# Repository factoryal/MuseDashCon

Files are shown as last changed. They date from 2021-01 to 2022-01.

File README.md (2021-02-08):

# MuseDashCon
MuseDashCon은 게임 MuseDash를 플레이하기 위한 커스텀 컨트롤러입니다.  
ArcadeBoard Type A 기반으로 만들었습니다.

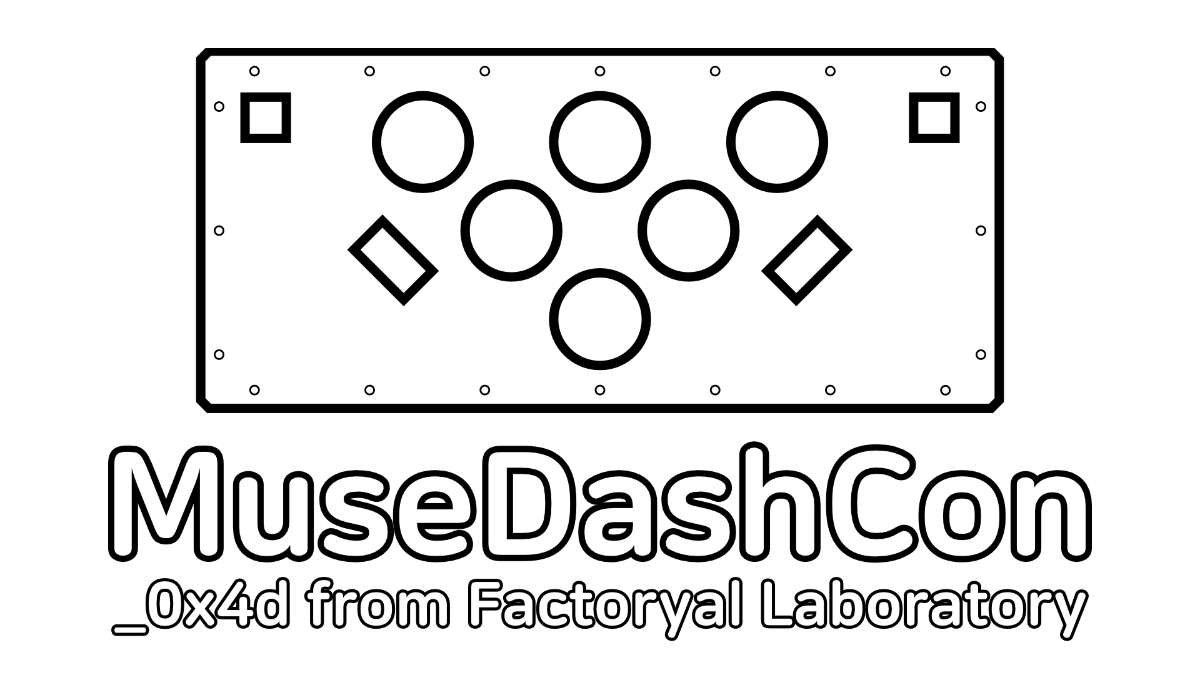
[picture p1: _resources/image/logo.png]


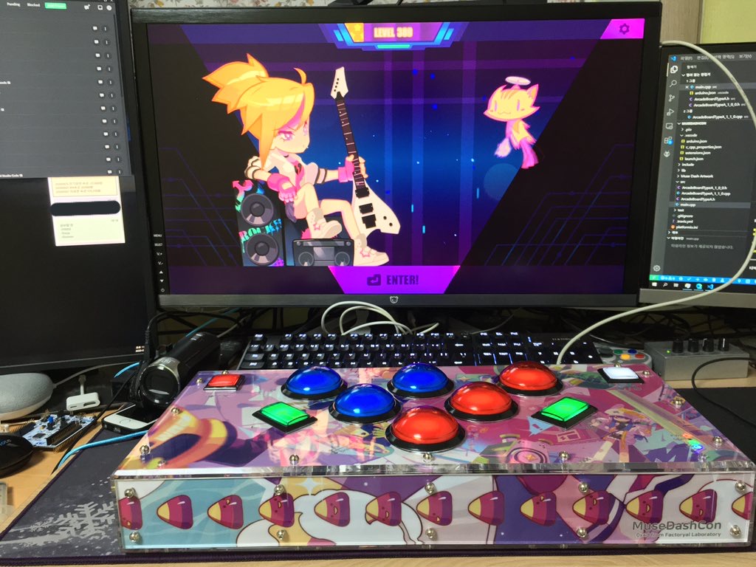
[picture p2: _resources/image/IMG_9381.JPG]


## Video
https://www.youtube.com/watch?v=jQfnqSeiyE0

[Muse Dash] Gaming Everything - Hard 8 w/ MuseDashCon (https://www.youtube.com/watch?v=-giunZwyiVg)

## Specs
Main Board: Arcade Board Type A v1.1.0 (Arduino Leonardo based)  
Button: IST 403, IST 405, IST 406 (GSM-V0303A06 Microswitch) (https://www.istmall.co.kr/goods/goods_list.php?cateCd=014008)  
Polling Rate: 1000Hz  
Interface: USB Type B  
Dimension: 460mm x 212mm x 74mm  

# Repository Includes...
**MuseDashCon** 리포지토리는 다음과 같은 자료가 저장되어 있습니다.

## Arduino 소스코드 (ArcadeBoard Type A)
Arduino Leonardo 기반 ArcadeBoard Type A 소스코드가 있습니다.  
PlatformIO 환경에서 개발하였으며, 아두이노 IDE에서 확인하려면 `src` 폴더를 다른 위치에 복사 후 폴더의 이름을 변경해주세요.  
이후 폴더 내의 `main.cpp` 파일 이름을 `(폴더 이름).ino`로 변경해주세요.

## dxf 도면 파일
외부 아크릴 레이저가공 및 이미지 출력에 필요한 dxf 도면 파일이 있습니다.  
`design/dxf` 폴더에 있습니다.

## 이미지 파일
외부 그림 출력에 사용된 이미지 파일이 `design/jpg` 폴더에 있습니다.

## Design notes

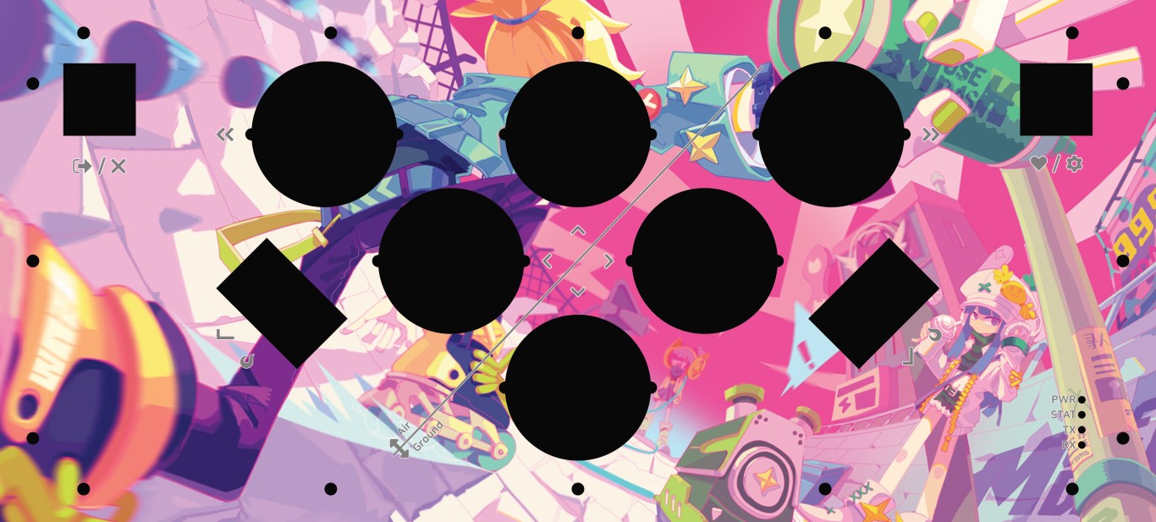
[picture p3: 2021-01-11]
design/jpg/top (Medium).jpg

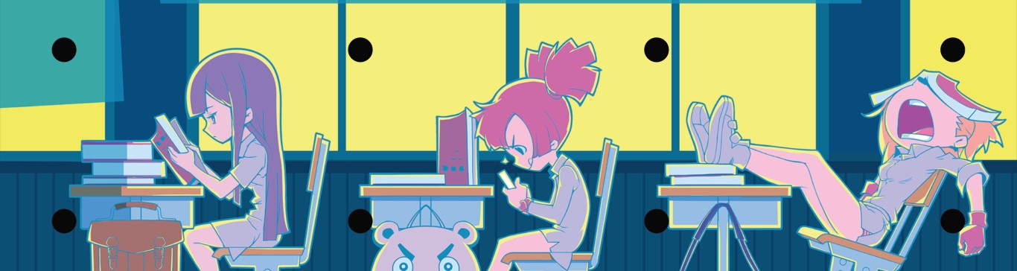
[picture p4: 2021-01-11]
design/jpg/left (Medium).jpg

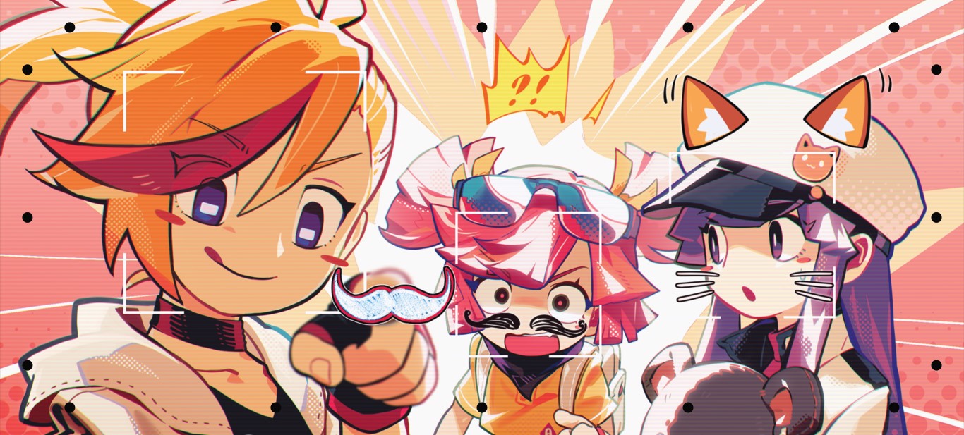
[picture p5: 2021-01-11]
design/jpg/bottom (Medium).jpg

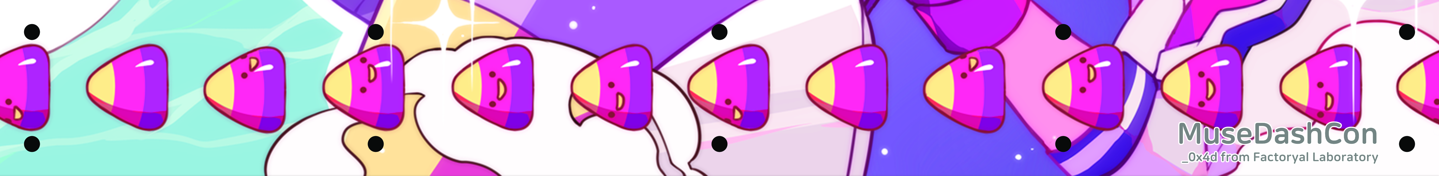
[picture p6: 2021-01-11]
design/jpg/front.jpg

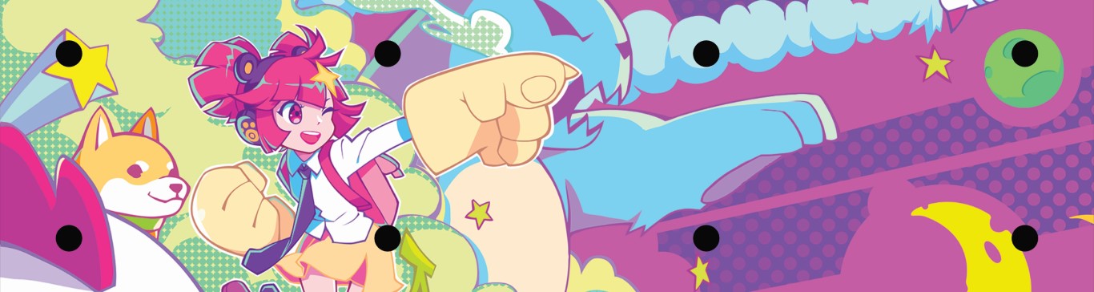
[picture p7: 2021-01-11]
design/jpg/right (Medium).jpg

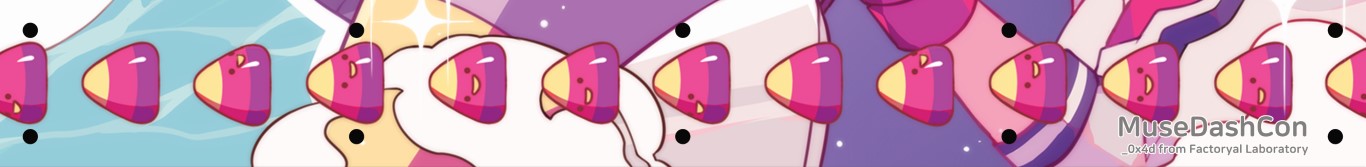
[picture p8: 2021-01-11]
design/jpg/front (Medium).jpg

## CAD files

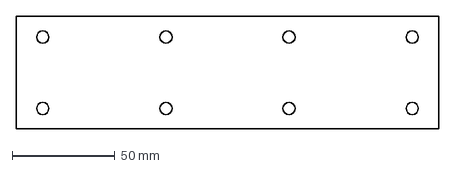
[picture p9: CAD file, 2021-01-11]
design/dxf/right.dxf
206.0 x 55.0 mm

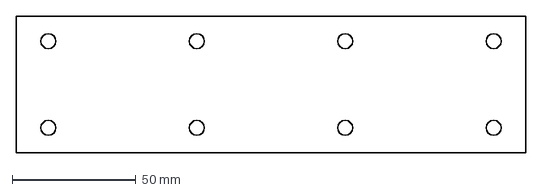
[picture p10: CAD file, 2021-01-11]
design/dxf/left.dxf
206.0 x 55.0 mm

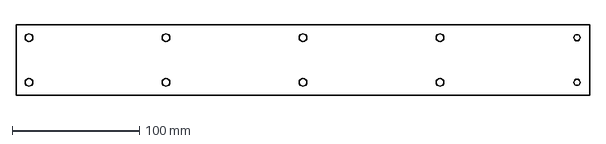
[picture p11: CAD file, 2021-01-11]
design/dxf/front.dxf
450.0 x 55.0 mm

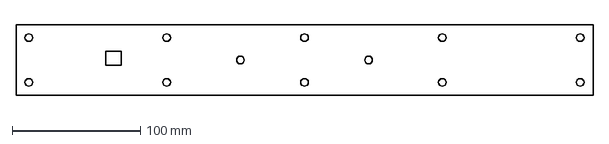
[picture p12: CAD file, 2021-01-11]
design/dxf/back.dxf
450.0 x 55.0 mm

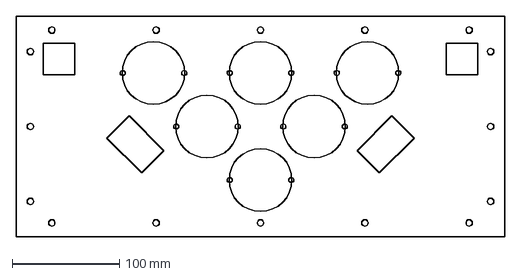
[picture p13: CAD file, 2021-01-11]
design/dxf/top.dxf
456.0 x 206.0 mm

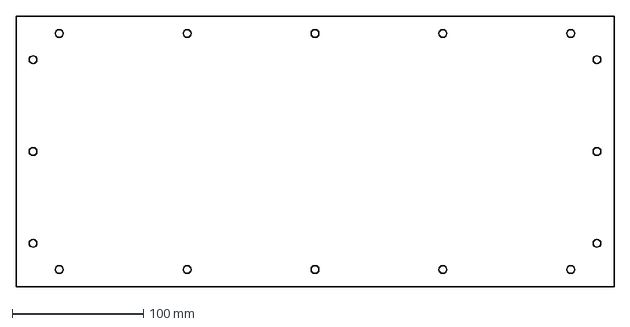
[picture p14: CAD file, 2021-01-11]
design/dxf/bottom.dxf
456.0 x 206.0 mm

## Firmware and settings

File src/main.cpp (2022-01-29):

#include <Arduino.h>
#include <Keyboard.h>

#define BOARD_MAJOR_VERSION 1
#define BOARD_MINOR_VERSION 1
#define BOARD_PATCH_VERSION 0
#include "ArcadeBoardTypeA.h"

#define IFD if(debug)

bool debug = false;

/***********************************************************
 * ┌──────────────────── MuseDashCon ───────────────────┐
 * │┌────┐       ┌────┐    ┌────┐    ┌────┐       ┌────┐│
 * ││ 00 │       │ 01 │    │ 02 │    │ 03 │       │ 04 ││
 * │└────┘       └────┘    └────┘    └────┘       └────┘│
 * │ L10     ┌────┐   ┌────┐    ┌────┐   ┌────┐    D11  │
 * │         │ 05 │   │ 06 │    │ 07 │   │ 08 │         │
 * │         └────┘   └────┘    └────┘   └────┘         │
 * │                       ┌────┐                       │
 * │                       │ 09 │                       │
 * │                       └────┘                       │
 * └────────────────────────────────────────────────────┘
 **********************************************************/
// Long Press 00: L10
// Double Press 04: D11

uint8_t keyBinds[12] = { 'k', 'q', 'w', 'e', \
						' ', KEY_RETURN, 'a', 'd', \
						KEY_RETURN, 's', KEY_ESC, KEY_TAB };

// uint8_t keyBinds[12] = { 'k', 'a', 'w', 'd', \
// 						' ', 'j', 's', 'w', \
// 						'j', 's', KEY_ESC, KEY_TAB };

// Variables for Long Press Feature Implementation
uint8_t k0_t = 0;
bool k0_p = 0;
uint8_t k1_t = 0;
uint8_t k1_t2 = 0;
bool k1_p = 0;
bool k1_lp = false;

uint8_t idle_led_val = 100;
uint8_t b_level = 0;

// Function Prototypes
void keyEvent(uint8_t swidx, uint8_t type);
void tick_loop();

// Run setup() once
void setup() {
	// Powering on with pressing switch #0 to enter debug mode
	if(!digitalRead(PIN_SW0)) debug = true;

	pinMode(LED_BUILTIN, OUTPUT);
	delay(1000);

	// if debug mode enabled
	if(debug) {
		Serial.begin(9600);
		while(!Serial) {
			PORTC ^= (1 << 7);
			delay(100);
		}
		Serial.println(F("DEBUG MODE ACTIVATED"));
	}

	IFD Serial.println(F("_0x4d's Arcade Board Type A"));

	// Initiating LED Controller
	IFD Serial.print(F("Initiate LED controller..."));
	int r;
	if((r = LED.init(0x4d)) != 0) {
		IFD Serial.println(F("failed"));
		IFD Serial.println(r);
	}
	else {
		for(int i = 0; i < 10; i++) {
			LED.setValue(i, 0);
		}
		LED.update();
		IFD Serial.println(F("success"));
		delay(1000);
	}

	// Initiating Switch Controller
	IFD Serial.print(F("Initiate Switch Controller..."));
	delay(100);
	Switch.init(POLLING_RATE_1000HZ);
	IFD Serial.println(F("success"));

	// Testing LED
	IFD Serial.print(F("LED testing..."));
	for(int i = 0; i < 10; i++) {
		LED.setValue(i, 255);
		LED.update();
		delay(100);
		LED.setValue(i, 30);
		LED.update();
		delay(10);
	}
	IFD Serial.println(F("done"));

	for(int i = 0; i < 10; i++) LED.setValue(i, 30);
	LED.update();
	delay(100);

	// Starting keyboard service
	Keyboard.begin();
	delay(100);

	// Add callback function to Swtich Controller
	Switch.setCallback(keyEvent);
	Switch.setCallbackOnTick(tick_loop);
	Switch.setInputDelay(20);
}

// Run loop() forever
void loop() {
	for(uint8_t i = 0; i < 16; i++) {
		if(LED.getValue(i) != 255) LED.setValue(i, idle_led_val);
	}
	LED.update();
	delay(16);
}

void keyEvent(uint8_t swidx, uint8_t type) {
	switch(type) {
		case FALLING:
		LED.setValue(swidx, 0xFF);
		if(swidx == 4) {
			if(k1_t > 0) { // BTN04 Double Tap
				k1_t = 0;
				k1_p = false;
				Keyboard.press(keyBinds[11]);
				Keyboard.release(keyBinds[11]);
			}
			else {
				k1_t = 64;
				k1_p = true;
			}
		}
		else {
			Keyboard.press(keyBinds[swidx]);
			if(swidx == 0) {
				k0_t = 125;
				k0_p = 1;
			}
		}
		break;

		case RISING:
		LED.setValue(swidx, idle_led_val);

		if(swidx == 4) {
			k1_p = false;
			if(k1_lp) {
				Keyboard.release(keyBinds[4]);
				k1_lp = false;
			}
		}
		else {
			Keyboard.release(keyBinds[swidx]);
			if(swidx == 0) {
				Keyboard.release(keyBinds[10]);
				k0_t = 125;
				k0_p = 0;
			}
		}
		break;
	}
}

void tick_loop() {
	static uint8_t t1 = 0;
	static uint8_t t2 = 10;
	static uint8_t t3 = 0;

	// on every 4 ticks
	if(++t1 == 4) {
		t1 = 0;

		if(k0_p == 1 && --k0_t == 0) Keyboard.press(keyBinds[10]);
		if(k1_t > 0) {
			if(--k1_t == 0) { // Timeout Reached
				if(!k1_p) { // BTN04 Single Tap
					Keyboard.press(keyBinds[4]);
					k1_t2 = 5;
				}
				else if(k1_p) { // BTN04 Long Press
					Keyboard.press(keyBinds[4]);
					k1_lp = true;
				}
			}
		}
		if(k1_t2 > 0) {
			if(--k1_t2 == 0) {
				Keyboard.release(keyBinds[4]);
			}
		}

		// on every 4 * 250 ticks
		if(++t2 == 250) {
			PORTC &= ~(1 << 7);
			if(abs(b_level - CdS.getBrightnessLevel()) > 0) {
				if(b_level > CdS.getBrightnessLevel()) b_level--;
				else b_level++;
			}
			idle_led_val = b_level * 7;
		}
		// on every 4 * 250 ticks
		if(++t3 == 250) {
			PORTC |= (1 << 7);
		}
	}
}

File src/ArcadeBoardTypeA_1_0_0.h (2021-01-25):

// --------------------------------------
//        ArcadeBoardTypeA v1.0.0
// --------------------------------------
// https://github.com/factoryal/Arcade-Board

#pragma once

#include "Arduino.h"
#include <Wire.h>

#define PIN_SW0 0    // PD2
#define PIN_SW1 1    // PD3
#define PIN_SW2 4    // PD4
#define PIN_SW3 12   // PD6
#define PIN_SW4 6    // PD7
#define PIN_SW5 SCK  // PB1
#define PIN_SW6 MOSI // PB2
#define PIN_SW7 MISO // PB3
#define PIN_SW8 8    // PB4
#define PIN_SW9 9    // PB5
#define PIN_SW10 10  // PB6
#define PIN_SW11 11  // PB7
#define PIN_SW12 A5  // PF0
#define PIN_SW13 A4  // PF1
#define PIN_SW14 A3  // PF4
#define PIN_SW15 A2  // PF5

#define PIN_LIGHT_SENSOR A1

#define POLLING_RATE_125HZ 2000
#define POLLING_RATE_250HZ 1000
#define POLLING_RATE_500HZ 500
#define POLLING_RATE_1000HZ 250
#define POLLING_RATE_2000HZ 125
#define CUSTOM_POLLING_RATE(x) (250000UL / x)


// http://ww1.microchip.com/downloads/en/devicedoc/atmel-7766-8-bit-avr-atmega16u4-32u4_datasheet.pdf

typedef uint16_t POLLING_RATE_TYPEDEF;

class SwitchController {
private:
	uint16_t sw_state_now = 0xFFFF;
	uint16_t sw_state_before = 0xFFFF;
	void (*_event_callback)(uint8_t, uint8_t) = NULL;
	void (*_tick_callback)() = NULL;
	uint8_t inputDelays[16] = { 0 };
	uint8_t inputDelayTick = 0;

public:
	SwitchController() {

	}

	void init(POLLING_RATE_TYPEDEF polling_rate) {
		cli();
		TCCR3A = (1 << WGM31);
		TCCR3B = (1 << WGM33) | (1 << WGM32) | (1 << CS31) | (1 << CS30);
		TIMSK3 = (1 << TOIE3);
		ICR3 = polling_rate - 1;
		sei();
	}

	void setInputDelay(uint8_t tick) {
		inputDelayTick = tick;
	}

	void update() {
		if(_tick_callback) _tick_callback();

		sw_state_now = \
					((uint16_t)(PINF & 0x30) << 10) | ((uint16_t)(PINF & 0x03) << 12) |\
					((uint16_t)(PINB & 0xFE) << 4) |\
					((PIND & 0xC0) >> 3) | ((PIND & 0x1C) >> 2);

		uint16_t mask = 0x0001;
		for(uint8_t i = 0; i < 16; i++, mask = mask << 1) {
			if(inputDelays[i]) {
				if(sw_state_before & mask) sw_state_now |= mask;
				else sw_state_now &= ~mask;
				inputDelays[i]--;
			}
		}

		uint16_t changes = sw_state_now ^ sw_state_before;
		if(changes) {
			uint16_t mask = 0x0001;
			for(uint8_t i = 0; i < 16; i++, mask = mask << 1) {
				if(_event_callback && (changes & mask) && inputDelays[i] == 0) {
					_event_callback(i, ((sw_state_now >> i) & 0x0001) | 0x0002);
					inputDelays[i] = inputDelayTick;
				}
			}
		}
		sw_state_before = sw_state_now;
	}

	void setCallback(void (*callback)(uint8_t swidx, uint8_t type)) {
		_event_callback = callback;
	}

	void setCallbackOnTick(void (*callback)()) {
		_tick_callback = callback;
	}

} Switch;


// https://www.nxp.com/docs/en/data-sheet/PCA9635.pdf

class LEDController {
private:
	uint8_t brightness[16] = { 0 };
	uint8_t addr;

public:
	LEDController() {
		Wire.begin();
		Wire.setTimeout(100);
	}

	int init(uint8_t address) {
		addr = address;
		Wire.beginTransmission(addr);
		int8_t r = Wire.endTransmission();
		if(!r) {
			setRegister(addr, 0x00, 0x00);
			setRegister(addr, 0x01, 0x14);
			for(uint8_t i = 0; i < 4; i++) {
				setRegister(addr, 0x14 + i, 0xFF);
			}
		}
		return r;
	}

	void setValue(uint8_t idx, uint8_t val) {
		brightness[idx] = val;
	}

	uint8_t getValue(uint8_t idx) {
		return brightness[idx];
	}

	int update() {
		Wire.beginTransmission(addr);
		Wire.write(0xA2);
		for(uint8_t i = 0; i < 16; i++) {
			Wire.write(brightness[i]);
		};                                                                
		return Wire.endTransmission();
	}

private:
	static uint8_t setRegister(uint8_t address, uint8_t reg, uint8_t val) {
		Wire.beginTransmission(address);
		Wire.write(reg);
		Wire.write(val);
		return Wire.endTransmission();
	}

} LED;

class LightSensor {
private:
	uint16_t adc_val = 0;
	uint8_t pin = 0;

public:
	LightSensor(uint8_t pin) {
		this->pin = pin;
	}

	uint16_t getBrightnessRaw() {
		return analogRead(pin);
	}
	
	uint8_t getBrightnessLevel() {
		return 0xf - ((getBrightnessRaw() & 0x2C0) >> 6);
	}

} CdS(PIN_LIGHT_SENSOR);

ISR(TIMER3_OVF_vect) {
	Switch.update();
}

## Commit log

2021-01-11 Mega Commit with library 1.0.0
    [#bottom.dxf, back.dxf, bottom.dxf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]
2021-01-11 dxf cache file removed
    [#bottom.dxf]
2021-01-11 Status LED behavior changes
2021-01-24 bugfix: custom polling rate
    [ArcadeBoardTypeA_1_0_0.h]
2021-02-07 LED ambient brightness control super simple
2021-03-10 removed unnecessary print messages
